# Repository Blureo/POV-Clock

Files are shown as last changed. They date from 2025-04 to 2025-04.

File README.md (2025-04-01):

# POV-Clock
Persistence-of-Vision LED Clock

This is an LED clock that makes use of persistence-of-vision to display time and temperature. The time can be set using the rotary encoder and 2 buttons (there are 3, but one was not used in the current iteration).

-------

This project was made in collaboration with 2 others: Joshua Sevick and Kolby Kriegelstein.

I, Jesse Thompson, was responsible for the PCB design, Real-time Clock (RTC), and implementing the rotary encoder's drivers in the RTC. All group members made their own drivers for the UART, ADC (for temperature), and bar of 16 LED's.

The design is based on the NXP MKL16Z MCU and was programmed in C++ using Keil uVision.

-------

## How to Use:
Time is set to zero by default. To set the time, press the edit button and use the rotary encoder to set hour and minute to desired number (switch between hour and minute mode using the hr/min button. If you experience difficulty seeing the time you are setting the clock to, connect a serial cable to the UART pins, and using an application such as PuTTY with a baud of 9600, you can see the time getting updated as you rotate the encoder. If using a terminal, connect the +5V pin. If using a PC, ***do not*** connect the +5V pin.

To see the time, flick your eyes across the LEDs. Moving one's head does not achieve the desired effect well. 

-------

## Current issues and future fixes
1. Edit mode spontaneously turns on despite the button not being pressed. Unsure at this time as to why this occurs. **Fix**: edit mode will only be on if the button is continuously pressed down.

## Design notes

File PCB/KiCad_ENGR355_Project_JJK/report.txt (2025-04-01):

Change symbol C4 from 'Device:C' to 'Device:C_Small': OK

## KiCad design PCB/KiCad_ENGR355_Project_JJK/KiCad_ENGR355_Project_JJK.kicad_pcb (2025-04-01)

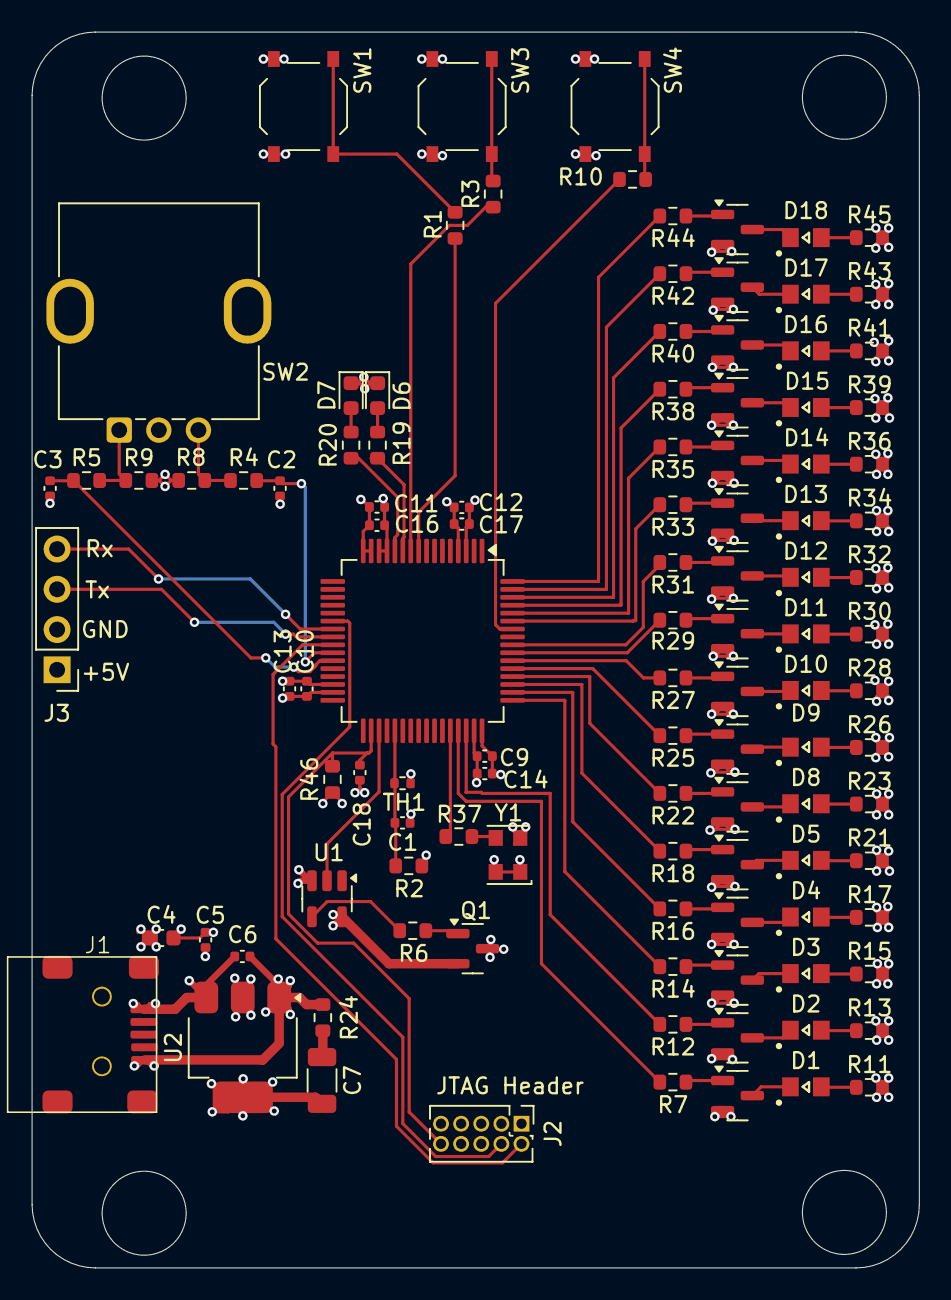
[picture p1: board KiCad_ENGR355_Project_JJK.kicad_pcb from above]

Board: 4 copper layers, 56.0 x 78.0 mm, 113 parts (0 on the bottom side), 94 nets.

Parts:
C1, C2, C3, C5, C9, C10, C16, C17: 0.1u; C_0402_1005Metric
C4: 4.7u; C_0603_1608Metric
C6, C11, C12, C13, C14, C18: 1u; C_0402_1005Metric
C7: 22u; C_1206_3216Metric
D1, D2, D3, D4, D5, D8, D9, D10, D11, D12, D13, D14, D15, D16, D17, D18: LED_Honglitronic_HL-PSC-2012
D6, D7: LED; LED_0603_1608Metric
H1, H2, H3, H4: MountingHole; MountingHole_5.3mm_M5
J1: USB_B_Mini; UX-144S-ACP5
J2: JTAG SWD; PinHeader_2x05_P1.27mm_Vertical
J3: Conn_01x04; PinHeader_1x04_P2.54mm_Vertical
Q1: AO3401A; SOT-23
Q2, Q3, Q4, Q5, Q6, Q7, Q8, Q9, Q10, Q11, Q12, Q13, Q14, Q15, Q16, Q17: AO3400A; SOT-23
R1, R3, R10: 330; R_0603_1608Metric
R2: 100k; R_0603_1608Metric
R4, R5, R8, R9: 4.7k; R_0603_1608Metric
R6: 47; R_0603_1608Metric
R7, R11, R12, R13, R14, R15, R16, R17, R18, R19, R20, R21, R22, R23, R25, R26, R27, R28, R29, R30, R31, R32, R33, R34, R35, R36, R37, R38, R39, R40, R41, R42, R43, R44, R45: 100; R_0603_1608Metric
R24: 1; R_0603_1608Metric
R46: 10k; R_0603_1608Metric
SW1, SW3, SW4: SW_Push; SW_Push_1P1T_XKB_TS-1187A
SW2: RotaryEncoder; RotaryEncoder_Bourns_Vertical_PEC12R-3x17F-Nxxxx
TH1: 100k; R_0402_1005Metric
U1: SN74LV1T34DBV; SOT-23-5
U2: AMS1117-3.3; SOT-223-3_TabPin2
U3: MKL16Z128VLH4; LQFP-64_10x10mm_P0.5mm
Y1: XO32; Oscillator_SMD_EuroQuartz_XO32-4Pin_3.2x2.5mm

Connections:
+3.3V: C7.1, C9.2, C10.2, C11.1, C12.1, C13.1, C14.1, C16.2, C17.2, J2.1, R2.2, R8.2, R9.2, R46.1, U2.2 (VO), U3.3 (VDD), U3.13 (VDDA), U3.14 (VREFH), U3.30 (VDD), U3.48 (VDD), Y1.1 (EN), Y1.4 (V+)
+5V: C4.2, C5.2, C6.1, J1.1 (VBUS), J3.1, Q1.2 (S), U1.5 (VCC), U2.3 (VI)
GND: C1.1, C2.1, C3.1, C4.1, C5.1, C6.2, C9.1, C10.1, C11.2, C12.2, C13.2, C14.2, C16.1, C17.1, C18.2, D6.1 (K), D7.1 (K), J1.5 (GND), J2.3, J2.5, J2.9, J3.2, Q2.2 (S), Q3.2 (S), Q4.2 (S), Q5.2 (S), Q6.2 (S), Q7.2 (S), Q8.2 (S), Q9.2 (S), Q10.2 (S), Q11.2 (S), Q12.2 (S), Q13.2 (S), Q14.2 (S), Q15.2 (S), Q16.2 (S), Q17.2 (S), R24.2, SW1.1, SW2.C, SW3.1, SW4.1, TH1.2, U1.3 (GND), U2.1 (GND), U3.4 (VSS), U3.15 (VREFL), U3.16 (VSSA), U3.31 (VSS), U3.47 (VSS), Y1.2 (GND)
unnamed: C7.2, R24.1
unnamed: D1.2 (A), R11.1
unnamed: D1.1 (K), Q2.3 (D)
unnamed: D2.2 (A), R13.1
unnamed: D2.1 (K), Q3.3 (D)
unnamed: D3.2 (A), R15.1
unnamed: D3.1 (K), Q4.3 (D)
unnamed: D4.2 (A), R17.1
unnamed: D4.1 (K), Q5.3 (D)
unnamed: D5.2 (A), R21.1
unnamed: D5.1 (K), Q6.3 (D)
unnamed: D6.2 (A), R19.2
unnamed: D7.2 (A), R20.2
unnamed: D8.2 (A), R23.1
unnamed: D8.1 (K), Q7.3 (D)
unnamed: D9.2 (A), R26.1
unnamed: D9.1 (K), Q8.3 (D)
unnamed: D10.2 (A), R28.1
unnamed: D10.1 (K), Q9.3 (D)
unnamed: D11.2 (A), R30.1
unnamed: D11.1 (K), Q10.3 (D)
unnamed: D12.2 (A), R32.1
unnamed: D12.1 (K), Q11.3 (D)
unnamed: D13.2 (A), R34.1
unnamed: D13.1 (K), Q12.3 (D)
unnamed: D14.2 (A), R36.1
unnamed: D14.1 (K), Q13.3 (D)
unnamed: D15.2 (A), R39.1
unnamed: D15.1 (K), Q14.3 (D)
unnamed: D16.2 (A), R41.1
unnamed: D16.1 (K), Q15.3 (D)
unnamed: D17.2 (A), R43.1
unnamed: D17.1 (K), Q16.3 (D)
unnamed: D18.2 (A), R45.1
unnamed: D18.1 (K), Q17.3 (D)
unnamed: J3.3, U3.24 (PTA2)
unnamed: J3.4, U3.23 (PTA1)
unnamed: Q1.3 (D), R11.2, R13.2, R15.2, R17.2, R21.2, R23.2, R26.2, R28.2, R30.2, R32.2, R34.2, R36.2, R39.2, R41.2, R43.2, R45.2
unnamed: Q1.1 (G), R6.1
unnamed: Q2.1 (G), R7.1
unnamed: Q3.1 (G), R12.1
unnamed: Q4.1 (G), R14.1
unnamed: Q5.1 (G), R16.1
unnamed: Q6.1 (G), R18.1
unnamed: Q7.1 (G), R22.1
unnamed: Q8.1 (G), R25.1
unnamed: Q9.1 (G), R27.1
unnamed: Q10.1 (G), R29.1
unnamed: Q11.1 (G), R31.1
unnamed: Q12.1 (G), R33.1
unnamed: Q13.1 (G), R35.1
unnamed: Q14.1 (G), R38.1
unnamed: Q15.1 (G), R40.1
unnamed: Q16.1 (G), R42.1
unnamed: Q17.1 (G), R44.1
unnamed: R1.1, SW1.2
unnamed: R3.1, SW3.2
unnamed: R4.1, R8.1, SW2.B
unnamed: R5.2, R9.1, SW2.A
unnamed: R10.1, SW4.2
unnamed: R6.2, U1.4 (Y)
unnamed: R37.2, U3.44 (PTC1/LLWU_P6/RTC_CLKIN)
unnamed: R37.1, Y1.3 (OUT)
PTA0: J2.4, U3.22 (PTA0)
PTA3: J2.2, U3.25 (PTA3)
PTA4: C2.2, R4.2, U3.26 (PTA4)
PTA5: C3.2, R5.1, U3.27 (PTA5)
PTA20: C18.1, J2.10, R46.2, U3.34 (PTA20)
PTB0: U1.2 (A), U3.35 (PTB0/LLWU_P5)
PTB2: C1.2, R2.1, TH1.1, U3.37 (PTB2)
PTC2: R7.2, U3.45 (PTC2)
PTC3: R12.2, U3.46 (PTC3/LLWU_P7)
PTC4: R14.2, U3.49 (PTC4/LLWU_P8)
PTC5: R16.2, U3.50 (PTC5/LLWU_P9)
PTC6: R18.2, U3.51 (PTC6/LLWU_P10)
PTC7: R22.2, U3.52 (PTC7)
PTC8: R25.2, U3.53 (PTC8)
PTC9: R27.2, U3.54 (PTC9)
PTC10: R29.2, U3.55 (PTC10)
PTC11: R31.2, U3.56 (PTC11)
PTD1: R10.2, U3.58 (PTD1)
PTD2: R33.2, U3.59 (PTD2)
PTD3: R35.2, U3.60 (PTD3)
PTD4: R38.2, U3.61 (PTD4/LLWU_P14)
PTD5: R40.2, U3.62 (PTD5)
PTD6: R42.2, U3.63 (PTD6/LLWU_P15)
PTD7: R44.2, U3.64 (PTD7)
PTE20: R1.2, U3.9 (PTE20)
PTE21: R3.2, U3.10 (PTE21)
PTE22: R19.1, U3.11 (PTE22)
PTE23: R20.1, U3.12 (PTE23)

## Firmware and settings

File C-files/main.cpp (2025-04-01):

#include <MKL16Z4.h>
#include <stdint.h>
#include "DLED.h"
#include "DUART.h"
#include "DADC.h"
#include "POVDisplay.h"
#include "dRTC.h"
#include "DRot.h"
 
DUART g_DUART;
DLED g_DLED;
DADC g_DADC;
POVDisplay g_POVDisplay;
dRTC g_RTC;
DRot g_DRot;
	
int main ()
{ 
	g_DUART.Init();
	g_DLED.Init();
	g_DADC.Init();
	g_DRot.Init();
	g_RTC.Init();
	g_POVDisplay.Init();
	g_POVDisplay.setDisplayTime(g_RTC.getTime());
	
	g_DLED.LEDBrightness(100);

	
	while(1)
	{

		// Final Main
		
		if (g_RTC.edit)
		{
			g_RTC.editTime();
		}
		//end final main

	}

} 

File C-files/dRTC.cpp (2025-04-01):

#include "dRTC.h"
#include "DRot.h"
#include <stdio.h>
#include <MKL16Z4.h>
#include "DLED.h"

dRTC::dRTC() // constructor
{
	edit = false; // edit mode off by default
	timeTypeEdit = true; // hour mode by default
	userHour = 0;
	userMinute = 0;
}

void dRTC::Init()
{
	SIM->SCGC5 |= SIM_SCGC5_PORTD_MASK; // enable PORTD for buttons
	SIM->SCGC5 |= SIM_SCGC5_PORTE_MASK; // enable PORTE for buttons
	SIM->SCGC5 |= SIM_SCGC5_PORTC_MASK; // enable PTC1
	SIM->SCGC6 |= SIM_SCGC6_RTC_MASK; // enabling software access and interrupts for RTC
	SIM->SOPT1 = (SIM->SOPT1 & ~SIM_SOPT1_OSC32KSEL_MASK) | SIM_SOPT1_OSC32KSEL(0b10); // selecting RTC_CLKIN
	
	
	PORTC->PCR[1] = (PORTC->PCR[1] & ~PORT_PCR_MUX_MASK) | PORT_PCR_MUX(1); // selecting alt 1
	PORTD->PCR[1] = (PORTD->PCR[1] & ~(PORT_PCR_MUX_MASK | PORT_PCR_PS_MASK| PORT_PCR_IRQC_MASK)) | PORT_PCR_MUX(0b001) | PORT_PCR_IRQC(0b1010)  | PORT_PCR_PS_MASK; // select GPIO functionality on PTD1, enable pull-up/down, select pull-down
	PORTE->PCR[20] = (PORTE->PCR[20] & ~(PORT_PCR_MUX_MASK | PORT_PCR_PS_MASK)) | PORT_PCR_MUX(0b001) | PORT_PCR_PE_MASK |  PORT_PCR_PS_MASK; // select GPIO functionality on PTE20, enable pull-up/down, select pull-down
	PORTE->PCR[21] = (PORTE->PCR[21] & ~(PORT_PCR_MUX_MASK | PORT_PCR_PS_MASK)) | PORT_PCR_MUX(0b001) | PORT_PCR_PE_MASK | PORT_PCR_PS_MASK; // select GPIO functionality on PTE21, enable pull-up/down, select pull-down
	
	PORTE->PCR[23] = (PORTE->PCR[22] &~PORT_PCR_MUX_MASK)|PORT_PCR_MUX(1);	// LED that flashes every second 
	PORTE->PCR[22] = (PORTE->PCR[23] &~PORT_PCR_MUX_MASK)|PORT_PCR_MUX(1);	// LED that is turned on and off during set time
	PTE->PDDR |= 0xC00000;
	// Default is input, so no need to set PDDR for buttons
	
	RTC->IER |= RTC_IER_TSIE_MASK; // enable time second interrupts
	
	RTC->TSR = 0; // set timer to initial value (zero or other)
	RTC->SR |= RTC_SR_TCE_MASK; // enable timer
	
	NVIC_EnableIRQ(RTC_Seconds_IRQn);
	NVIC_EnableIRQ(PORTC_PORTD_IRQn);
}


// setTime needs to be a loop which is active once edit button is pressed and until its pressed again
// while its high it constantly updates class variable time according to user inputs
void dRTC::editTime()
{
	userHour = RTC->TSR/3600;
	userMinute = (RTC->TSR % 3600) / 60;
	
	PTE->PSOR |= 0x800000;
	g_DLED.LEDBrightness(20);
	while (edit)
	{
		if (timeTypeEdit) // edit hours
		{
			userHour = g_DRot.Get(); // set userHour to encoder value constantly until mode is changed or edit mode is exited
			if (userHour > 23)
				userHour = 23;
		}
		else // edit minute
		{
			userMinute = g_DRot.Get(); // set userMinute to encoder value constantly until mode is changed or edit mode is exited
		}
		
		time = (userHour*100) + userMinute; // set time variable so clockface can read it and send it while editing
	} // while (edit)
	RTC->SR &= ~RTC_SR_TCE_MASK; // disable timer
	RTC->TSR = userHour*3600 + userMinute*60; // update RTC with new time
	RTC->SR |= RTC_SR_TCE_MASK; // enable timer
	PTE->PCOR |= 0x800000;
	g_DLED.LEDBrightness(100);
} // function

int dRTC::getTime()
{
	int temp = RTC->TSR;
	int hour;
	int minute;
	
	if (edit)
		return time;
	else
	{
		hour = temp/3600; // set hours
		minute = (temp % 3600) / 60; // set minutes
		return (100*hour + minute);
	}
}

int dRTC::getRTC()
{
	return RTC->TSR;
}

void dRTC::editToggle()
{
	g_RTC.edit = !g_RTC.edit;
}


void dRTC::timeTypeToggle()
{
	timeTypeEdit = !timeTypeEdit;
}
